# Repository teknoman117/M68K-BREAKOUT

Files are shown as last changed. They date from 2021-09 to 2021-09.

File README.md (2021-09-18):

# M68K-BUS-VOLTAGE-CONVERTER

A breakout board for the MC68010 that drops the 5V TTL bus voltages to a 3.3V CMOS bus you can use with an FPGA.

Licensed under CC-BY-SA 4.0

## Pins

All MC68010 signals are converted with the exception of the MC6800 peripheral interface pins. VMA and E are left floating, and VMA is tied to 5V through a 2K2 resistor, which does prevent the use of autovectored interrupts. However, considering it's attached to an FPGA, a proper interrupt controller is a simple thing to add.

The RESET and HALT pins are able to be driven by the M68K itself, or by the FPGA. There are "RESET_OUT" and "HALT_OUT" pins which output the converted state of the pins, and "RESET_IN" and "HALT_IN" which connect to an inverter with open-collector outputs, allowing the FPGA to drive them low.

### Assembled
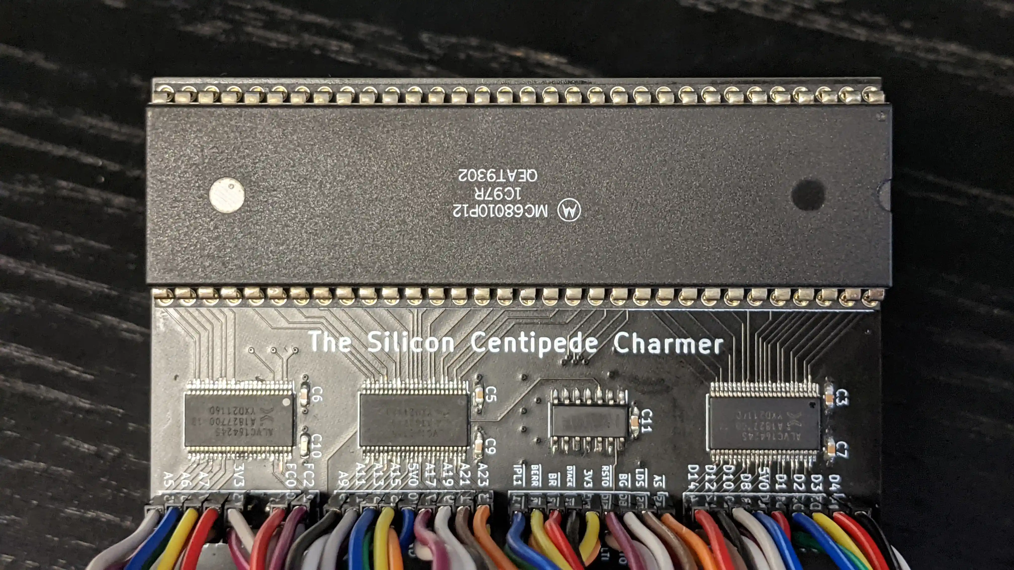
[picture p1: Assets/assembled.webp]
Assembled


### PCB
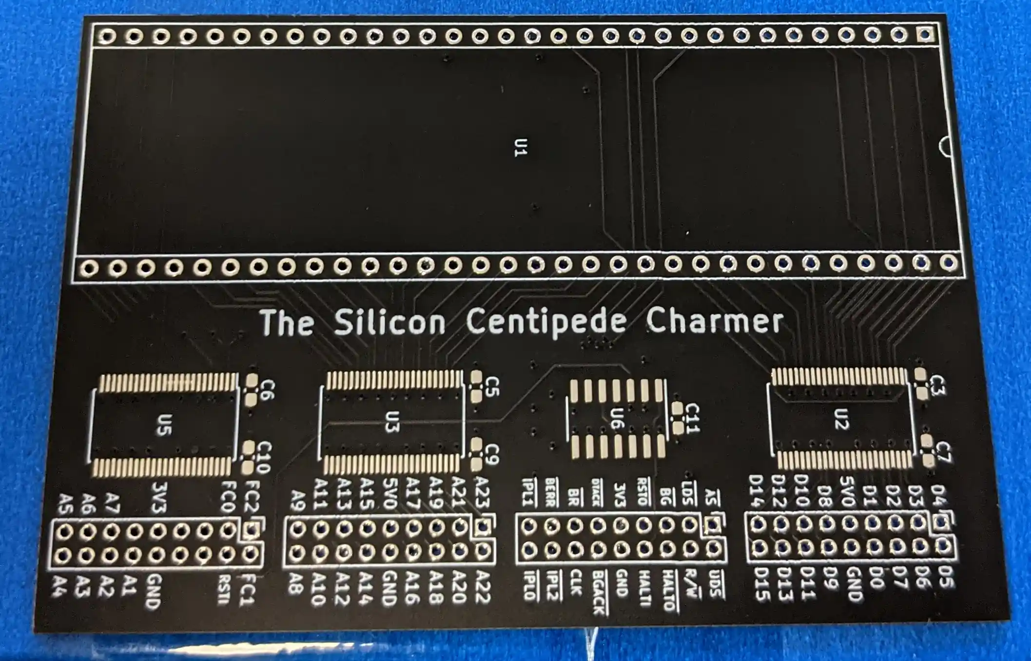
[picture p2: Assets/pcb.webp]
PCB


### Schematic
Schematic

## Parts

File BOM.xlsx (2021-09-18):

Reference | Quantity | Value | Footprint | Datasheet | Link | Mouser_PN
C1 C2 C3 C4 C5 C6 C7 C8 C9 C10 C11 | 11 | 100nF | Capacitor_SMD:C_0603_1608Metric_Pad1.08x0.95mm_HandSolder | https://product.tdk.com/system/files/dam/doc/product/capacitor/ceramic/mlcc/catalog/mlcc_commercial_general_en.pdf | https://www.mouser.com/ProductDetail/810-C1608X7R1E104K | 810-C1608X7R1E104K
J1 J2 J3 J4 | 4 | Conn_02x09_Odd_Even | Connector_PinHeader_2.00mm:PinHeader_2x09_P2.00mm_Vertical |  | https://www.amazon.com/Uxcell-a15062900ux0315-Single-Straight-Connector/dp/B012TBLZTC/
R1 R2 R3 | 3 | 2.2K | Resistor_SMD:R_0603_1608Metric_Pad0.98x0.95mm_HandSolder | https://www.mouser.com/datasheet/2/54/crxxxxx-1858361.pdf | https://www.mouser.com/ProductDetail/Bourns/CR0603-FX-2201ELF | 652-CR0603FX-2201ELF
U1 | 1 | 68010D | Package_DIP:DIP-64_W22.86mm_Socket | https://www.nxp.com/docs/en/reference-manual/MC68000UM.pdf | https://www.mouser.com/ProductDetail/575-193964 | 575-193964
U2 U3 U4 U5 | 4 | 74ALVC164245 | Package_SO:TSSOP-48_6.1x12.5mm_P0.5mm | https://www.mouser.com/datasheet/2/916/74ALVC164245-1318594.pdf | https://www.mouser.com/ProductDetail/771-74ALVC164245 | 771-74ALVC164245
U6 | 1 | 74LVC06 | Package_SO:SOIC-14_3.9x8.7mm_P1.27mm | https://www.ti.com/lit/ds/symlink/sn74lvc06a.pdf | https://www.mouser.com/ProductDetail/595-SN74LVC06AD | 595-SN74LVC06AD

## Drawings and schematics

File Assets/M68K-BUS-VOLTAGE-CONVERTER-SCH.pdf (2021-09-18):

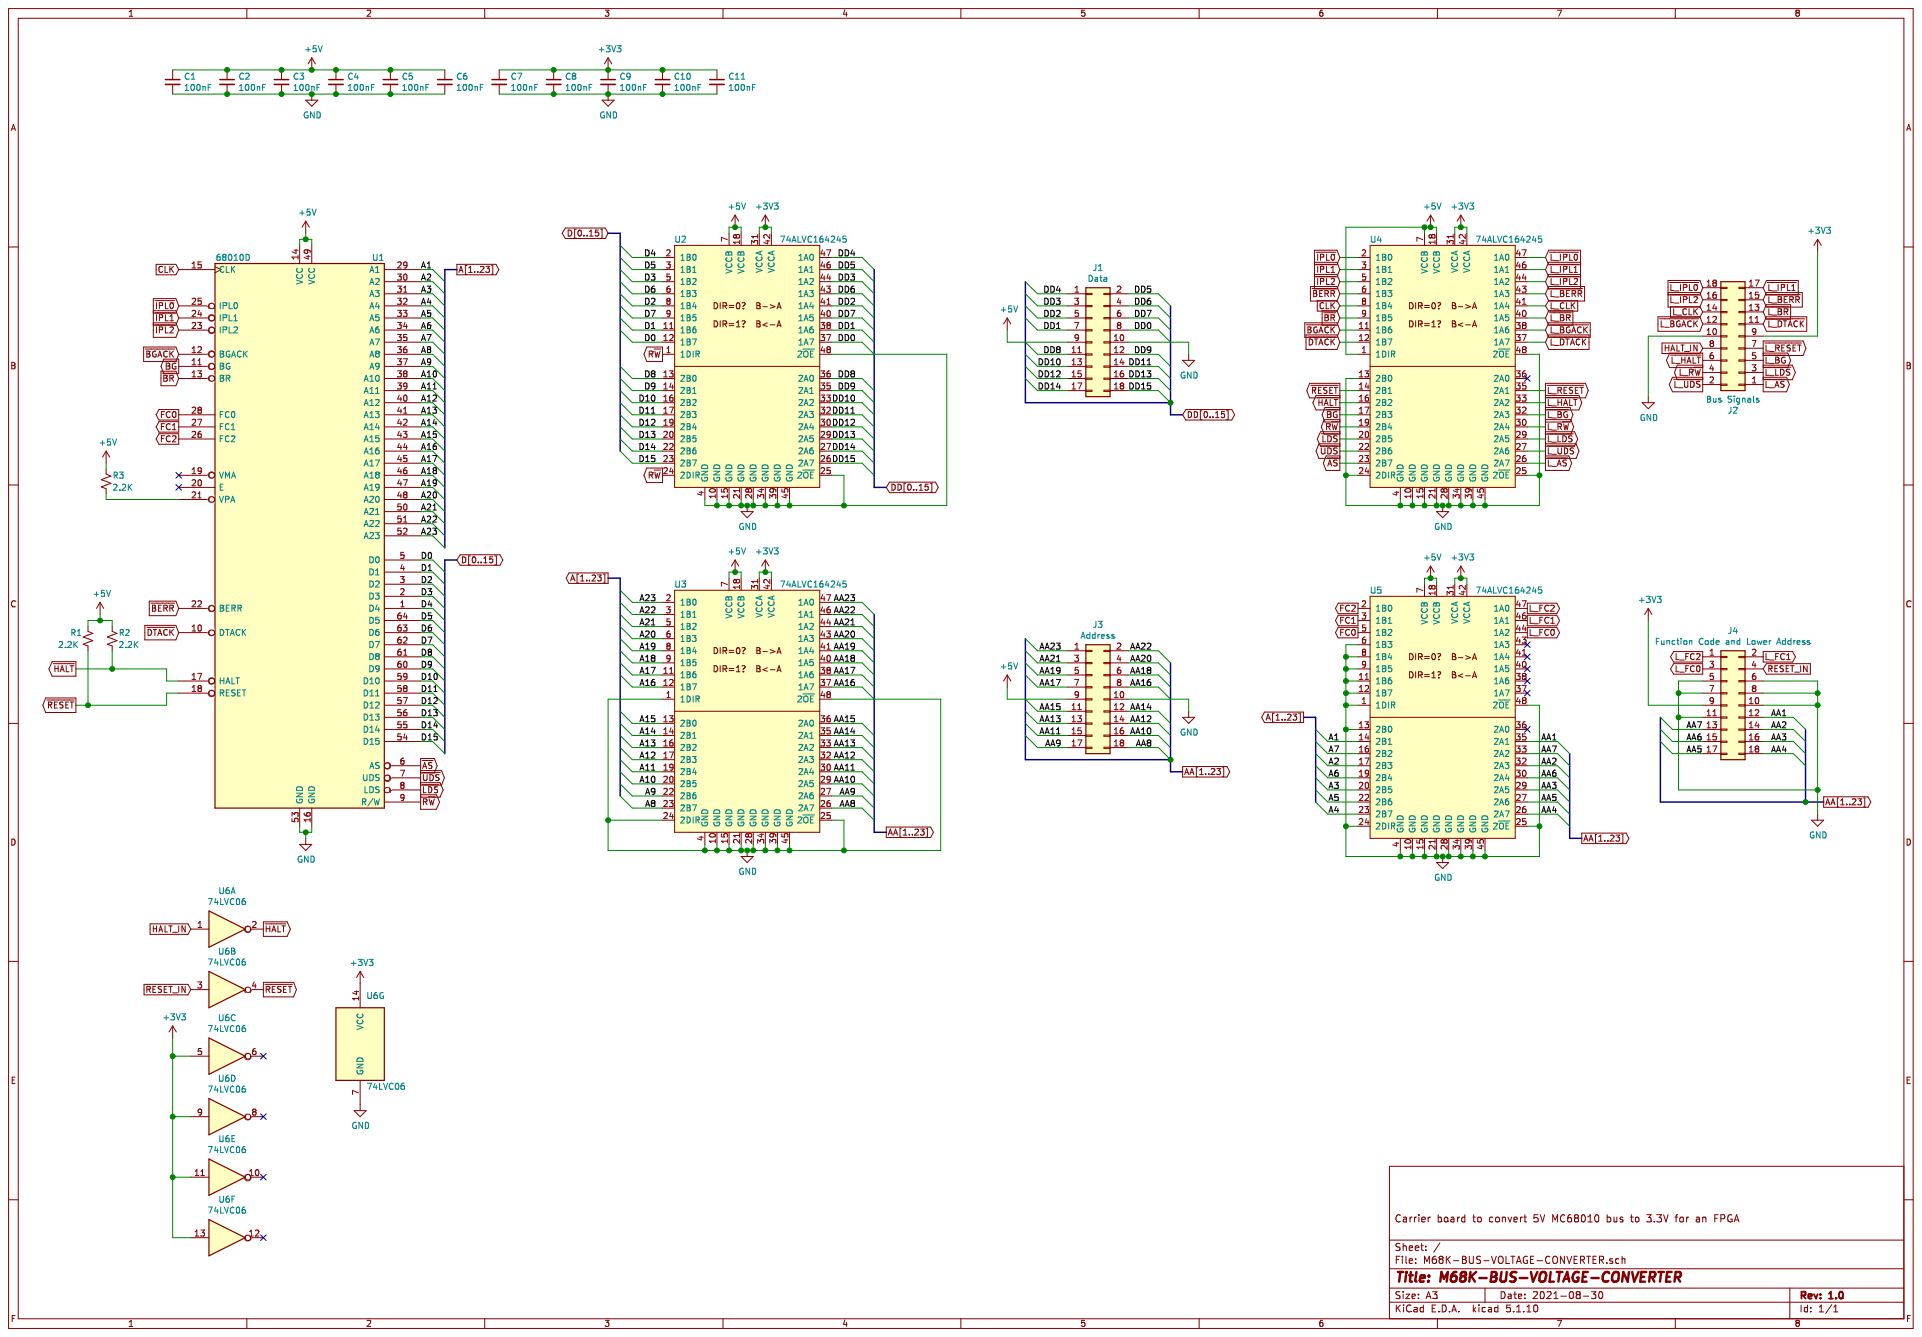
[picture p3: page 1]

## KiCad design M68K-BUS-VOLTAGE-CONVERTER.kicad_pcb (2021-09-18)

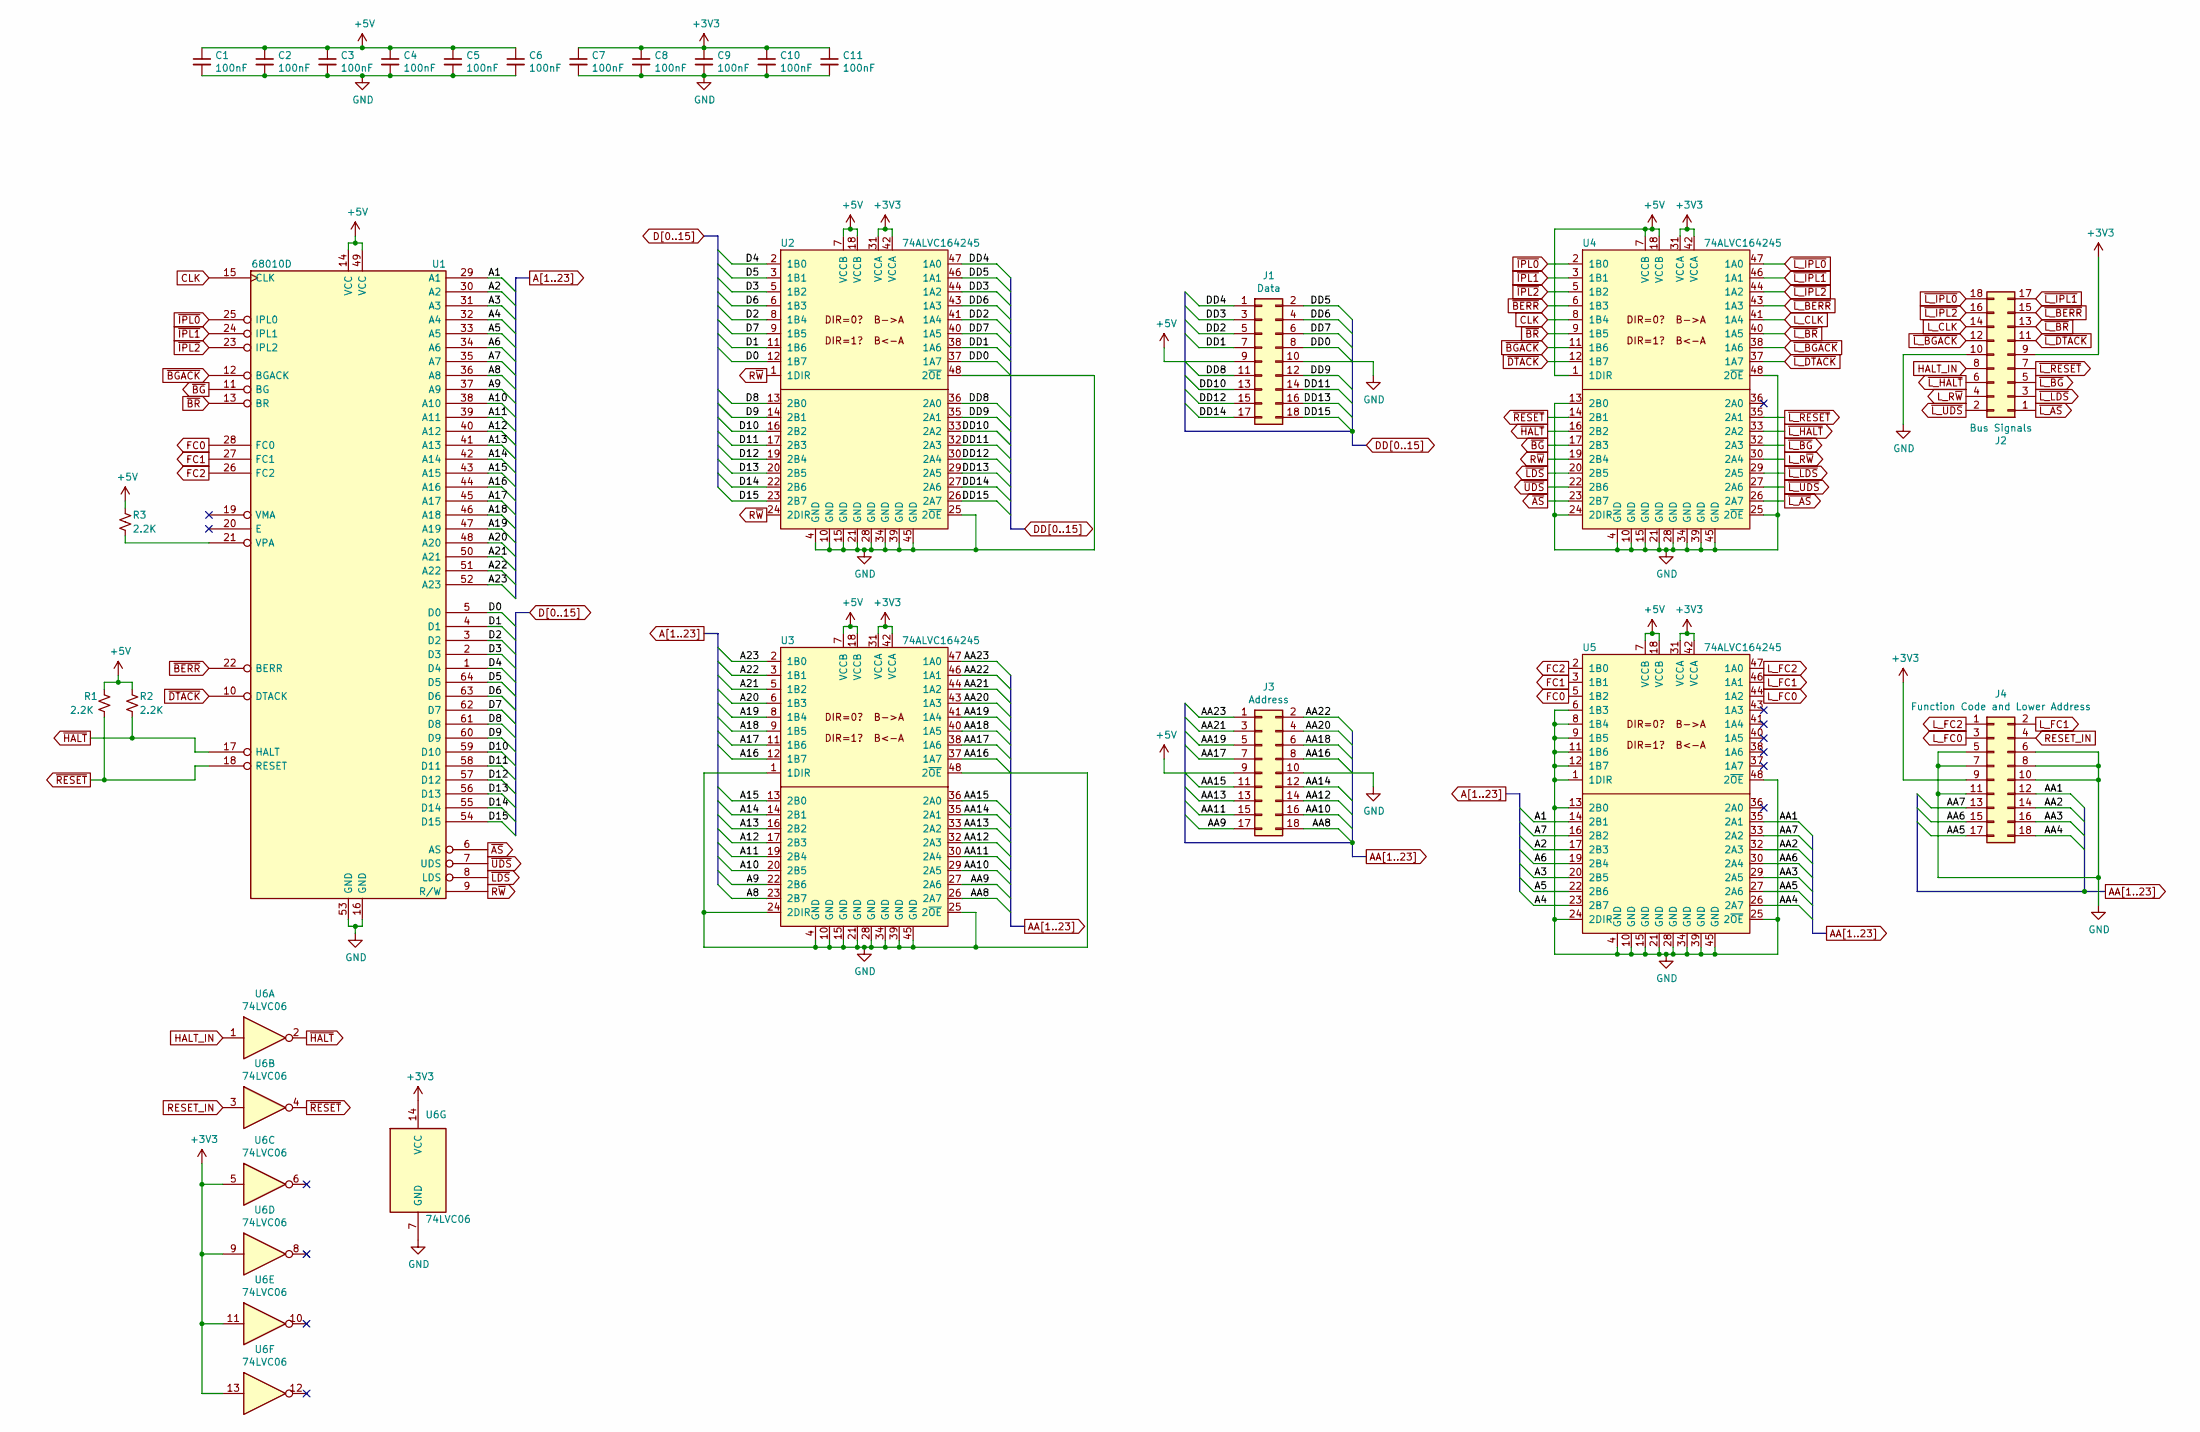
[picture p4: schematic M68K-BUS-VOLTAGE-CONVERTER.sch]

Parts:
C1, C2, C3, C4, C5, C6, C7, C8, C9, C10, C11: 100nF; C_0603_1608Metric_Pad1.08x0.95mm_HandSolder
J1: Data; PinHeader_2x09_P2.00mm_Vertical
J2: Bus Signals; PinHeader_2x09_P2.00mm_Vertical
J3: Address; PinHeader_2x09_P2.00mm_Vertical
J4: Function Code and Lower Address; PinHeader_2x09_P2.00mm_Vertical
R1, R2, R3: 2.2K; R_0603_1608Metric_Pad0.98x0.95mm_HandSolder
U1: 68010D; DIP-64_W22.86mm_Socket
U2, U3, U4, U5: 74ALVC164245; TSSOP-48_6.1x12.5mm_P0.5mm
U6: 74LVC06; SOIC-14_3.9x8.7mm_P1.27mm

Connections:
+3V3: C7.1, C8.1, C9.1, C10.1, C11.1, J2.9, J4.9, U2.31 (VCCA), U2.42 (VCCA), U3.31 (VCCA), U3.42 (VCCA), U4.31 (VCCA), U4.42 (VCCA), U5.31 (VCCA), U5.42 (VCCA), U6.5, U6.9, U6.11, U6.13, U6.14 (VCC)
+5V: C1.1, C2.1, C3.1, C4.1, C5.1, C6.1, J1.9, J3.9, R1.1, R2.1, R3.1, U1.14 (VCC), U1.49 (VCC), U2.7 (VCCB), U2.18 (VCCB), U3.7 (VCCB), U3.18 (VCCB), U4.1 (1DIR), U4.7 (VCCB), U4.18 (VCCB), U5.7 (VCCB), U5.18 (VCCB)
A1: U1.29 (A1), U5.14 (2B1)
A2: U1.30 (A2), U5.17 (2B3)
A3: U1.31 (A3), U5.20 (2B5)
A4: U1.32 (A4), U5.23 (2B7)
A5: U1.33 (A5), U5.22 (2B6)
A6: U1.34 (A6), U5.19 (2B4)
A7: U1.35 (A7), U5.16 (2B2)
A8: U1.36 (A8), U3.23 (2B7)
A9: U1.37 (A9), U3.22 (2B6)
A10: U1.38 (A10), U3.20 (2B5)
A11: U1.39 (A11), U3.19 (2B4)
A12: U1.40 (A12), U3.17 (2B3)
A13: U1.41 (A13), U3.16 (2B2)
A14: U1.42 (A14), U3.14 (2B1)
A15: U1.43 (A15), U3.13 (2B0)
A16: U1.44 (A16), U3.12 (1B7)
A17: U1.45 (A17), U3.11 (1B6)
A18: U1.46 (A18), U3.9 (1B5)
A19: U1.47 (A19), U3.8 (1B4)
A20: U1.48 (A20), U3.6 (1B3)
A21: U1.50 (A21), U3.5 (1B2)
A22: U1.51 (A22), U3.3 (1B1)
A23: U1.52 (A23), U3.2 (1B0)
AA1: J4.12, U5.35 (2A1)
AA2: J4.14, U5.32 (2A3)
AA3: J4.16, U5.29 (2A5)
AA4: J4.18, U5.26 (2A7)
AA5: J4.17, U5.27 (2A6)
AA6: J4.15, U5.30 (2A4)
AA7: J4.13, U5.33 (2A2)
AA8: J3.18, U3.26 (2A7)
AA9: J3.17, U3.27 (2A6)
AA10: J3.16, U3.29 (2A5)
AA11: J3.15, U3.30 (2A4)
AA12: J3.14, U3.32 (2A3)
AA13: J3.13, U3.33 (2A2)
AA14: J3.12, U3.35 (2A1)
AA15: J3.11, U3.36 (2A0)
AA16: J3.8, U3.37 (1A7)
AA17: J3.7, U3.38 (1A6)
AA18: J3.6, U3.40 (1A5)
AA19: J3.5, U3.41 (1A4)
AA20: J3.4, U3.43 (1A3)
AA21: J3.3, U3.44 (1A2)
AA22: J3.2, U3.46 (1A1)
AA23: J3.1, U3.47 (1A0)
CLK: U1.15 (CLK), U4.8 (1B4)
D0: U1.5 (D0), U2.12 (1B7)
D1: U1.4 (D1), U2.11 (1B6)
D2: U1.3 (D2), U2.8 (1B4)
D3: U1.2 (D3), U2.5 (1B2)
D4: U1.1 (D4), U2.2 (1B0)
D5: U1.64 (D5), U2.3 (1B1)
D6: U1.63 (D6), U2.6 (1B3)
D7: U1.62 (D7), U2.9 (1B5)
D8: U1.61 (D8), U2.13 (2B0)
D9: U1.60 (D9), U2.14 (2B1)
D10: U1.59 (D10), U2.16 (2B2)
D11: U1.58 (D11), U2.17 (2B3)
D12: U1.57 (D12), U2.19 (2B4)
D13: U1.56 (D13), U2.20 (2B5)
D14: U1.55 (D14), U2.22 (2B6)
D15: U1.54 (D15), U2.23 (2B7)
DD0: J1.8, U2.37 (1A7)
DD1: J1.7, U2.38 (1A6)
DD2: J1.5, U2.41 (1A4)
DD3: J1.3, U2.44 (1A2)
DD4: J1.1, U2.47 (1A0)
DD5: J1.2, U2.46 (1A1)
DD6: J1.4, U2.43 (1A3)
DD7: J1.6, U2.40 (1A5)
DD8: J1.11, U2.36 (2A0)
DD9: J1.12, U2.35 (2A1)
DD10: J1.13, U2.33 (2A2)
DD11: J1.14, U2.32 (2A3)
DD12: J1.15, U2.30 (2A4)
DD13: J1.16, U2.29 (2A5)
DD14: J1.17, U2.27 (2A6)
DD15: J1.18, U2.26 (2A7)
FC0: U1.28 (FC0), U5.5 (1B2)
FC1: U1.27 (FC1), U5.3 (1B1)
FC2: U1.26 (FC2), U5.2 (1B0)
GND: C1.2, C2.2, C3.2, C4.2, C5.2, C6.2, C7.2, C8.2, C9.2, C10.2, C11.2, J1.10, J2.10, J3.10, J4.5, J4.6, J4.7, J4.8, J4.10, J4.11, U1.16 (GND), U1.53 (GND), U2.4 (GND), U2.10 (GND), U2.15 (GND), U2.21 (GND), U2.25 (2~OE), U2.28 (GND), U2.34 (GND), U2.39 (GND), U2.45 (GND), U2.48 (2~OE), U3.1 (1DIR), U3.4 (GND), U3.10 (GND), U3.15 (GND), U3.21 (GND), U3.24 (2DIR), U3.25 (2~OE), U3.28 (GND), U3.34 (GND), U3.39 (GND), U3.45 (GND), U3.48 (2~OE), U4.4 (GND), U4.10 (GND), U4.13 (2B0), U4.15 (GND), U4.21 (GND), U4.24 (2DIR), U4.25 (2~OE), U4.28 (GND), U4.34 (GND), U4.39 (GND), U4.45 (GND), U4.48 (2~OE), U5.1 (1DIR), U5.4 (GND), U5.6 (1B3), U5.8 (1B4), U5.9 (1B5), U5.10 (GND), U5.11 (1B6), U5.12 (1B7), U5.13 (2B0), U5.15 (GND), U5.21 (GND), U5.24 (2DIR), U5.25 (2~OE), U5.28 (GND), U5.34 (GND), U5.39 (GND), U5.45 (GND), U5.48 (2~OE), U6.7 (GND)
HALT_IN: J2.8, U6.1
L_CLK: J2.14, U4.41 (1A4)
L_FC0: J4.3, U5.44 (1A2)
L_FC1: J4.2, U5.46 (1A1)
L_FC2: J4.1, U5.47 (1A0)
L_R~W: J2.4, U4.30 (2A4)
unnamed: R3.2, U1.21 (VPA)
RESET_IN: J4.4, U6.3
R~W: U1.9 (R/W), U2.1 (1DIR), U2.24 (2DIR), U4.19 (2B4)
~AS: U1.6 (AS), U4.23 (2B7)
~BERR: U1.22 (BERR), U4.6 (1B3)
~BG: U1.11 (BG), U4.17 (2B3)
~BGACK: U1.12 (BGACK), U4.11 (1B6)
~BR: U1.13 (BR), U4.9 (1B5)
~DTACK: U1.10 (DTACK), U4.12 (1B7)
~HALT: R2.2, U1.17 (HALT), U4.16 (2B2), U6.2
~IPL0: U1.25 (IPL0), U4.2 (1B0)
~IPL1: U1.24 (IPL1), U4.3 (1B1)
~IPL2: U1.23 (IPL2), U4.5 (1B2)
~LDS: U1.8 (LDS), U4.20 (2B5)
~L_AS: J2.1, U4.26 (2A7)
~L_BERR: J2.15, U4.43 (1A3)
~L_BG: J2.5, U4.32 (2A3)
~L_BGACK: J2.12, U4.38 (1A6)
~L_BR: J2.13, U4.40 (1A5)
~L_DTACK: J2.11, U4.37 (1A7)
~L_HALT: J2.6, U4.33 (2A2)
~L_IPL0: J2.18, U4.47 (1A0)
~L_IPL1: J2.17, U4.46 (1A1)
~L_IPL2: J2.16, U4.44 (1A2)
~L_LDS: J2.3, U4.29 (2A5)
~L_RESET: J2.7, U4.35 (2A1)
~L_UDS: J2.2, U4.27 (2A6)
~RESET: R1.2, U1.18 (RESET), U4.14 (2B1), U6.4
~UDS: U1.7 (UDS), U4.22 (2B6)

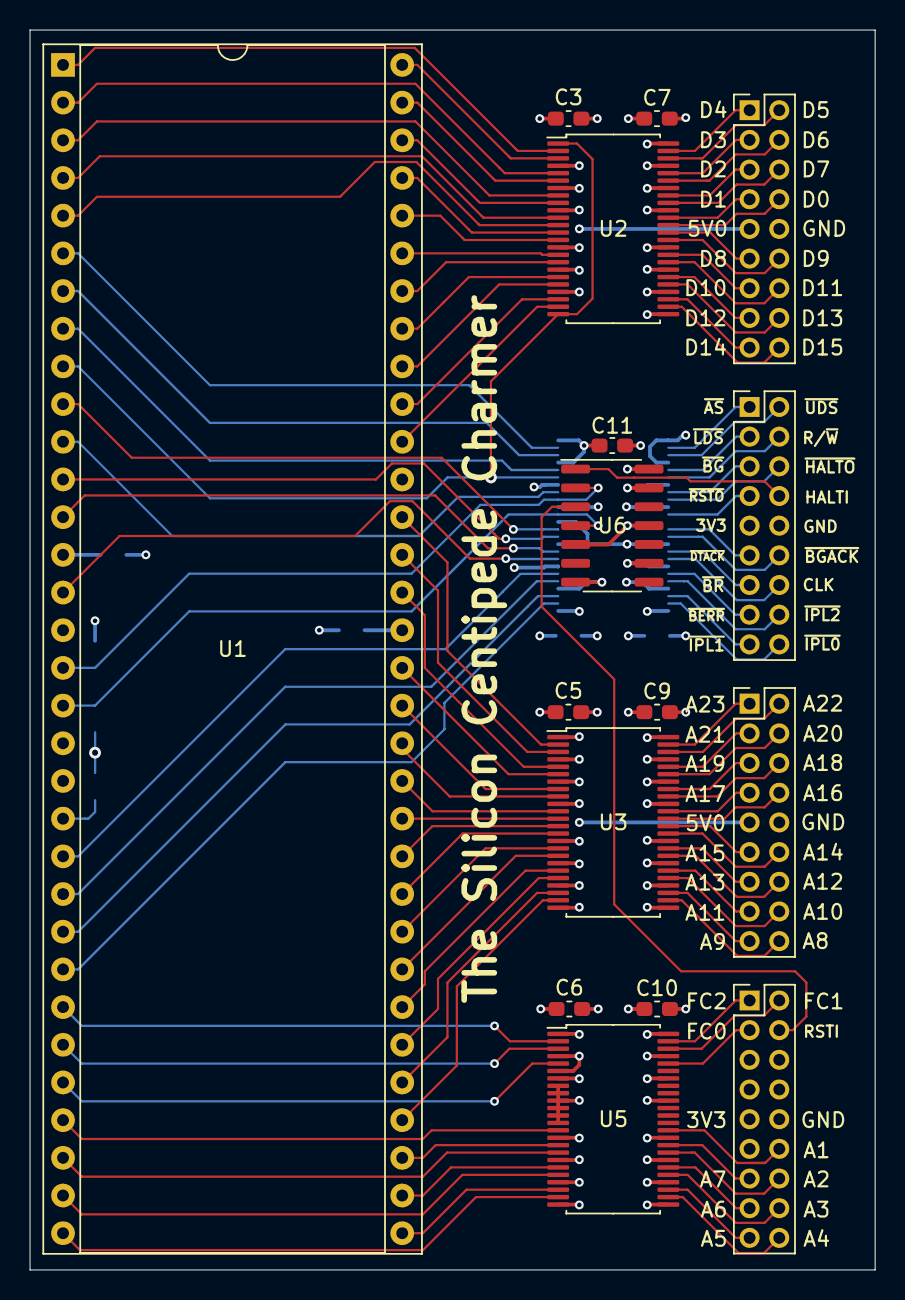
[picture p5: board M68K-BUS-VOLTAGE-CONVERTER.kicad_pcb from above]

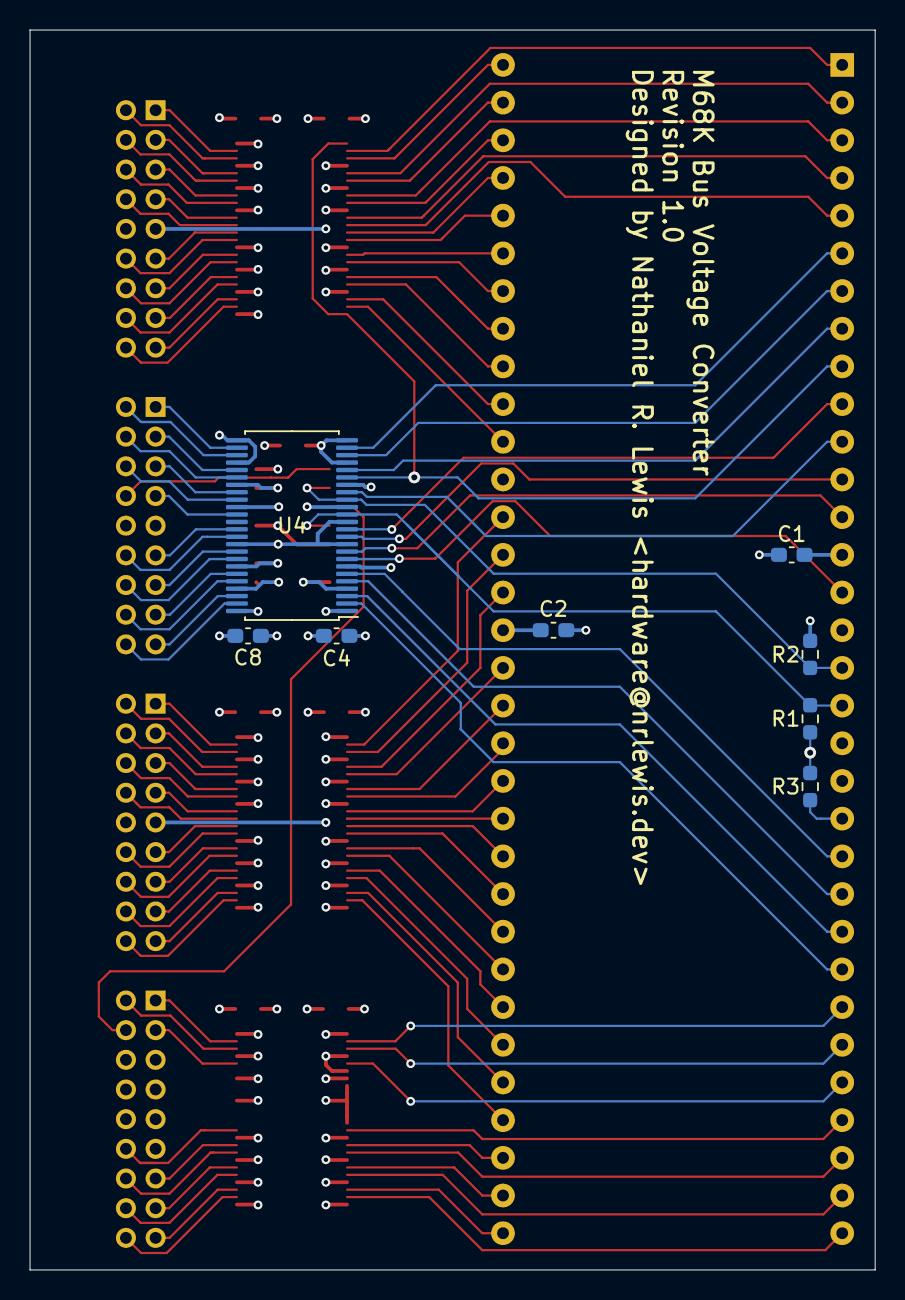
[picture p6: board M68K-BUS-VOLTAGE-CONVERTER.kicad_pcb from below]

Board: 4 copper layers, 57.0 x 83.6 mm, 24 parts (8 on the bottom side), 120 nets.

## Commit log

2021-08-28 first commit (board not complete)
    [M68K-BREAKOUT.kicad_pcb, M68K-BREAKOUT.sch]
2021-08-30 complete electrical layout for the silicon centipede charmer
    [M68K-BREAKOUT.kicad_pcb, M68K-BREAKOUT.sch]
2021-08-30 some trace cleanup, state at manufacturing
    [M68K-BREAKOUT-B_Cu.gbl, M68K-BREAKOUT-B_Mask.gbs, M68K-BREAKOUT-B_Paste.gbp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]
2021-09-15 add pictures of assembled board
2021-09-18 rename to M68K-BUS-VOLTAGE-CONVERTER and add schematic
    [M68K-BREAKOUT.kicad_pcb, M68K-BUS-VOLTAGE-CONVERTER.kicad_pcb, M68K-BUS-VOLTAGE-CONVERTER.sch]
2021-09-18 more pin description
2021-09-18 Added Bill-of-Materials
    [BOM.xlsx, M68K-BUS-VOLTAGE-CONVERTER.sch]
